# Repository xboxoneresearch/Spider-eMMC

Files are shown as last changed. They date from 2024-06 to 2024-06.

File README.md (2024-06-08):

# Spider-eMMC
KiCad 7.0 projects for SpiderUnifiedBoard and SpiderCarrierBoard, Xbox One eMMC replacement and repair boards.

_Note_: these projects are uncompleted and provided AS-IS. 

## Why?
Lack of time, resources and motivation to finish the project. Passing off the torch.
This was meant to be a complete solution to repair Xbox One consoles with damaged / degraded eMMCs. The main board would be put in the console (with minimal soldering needed), and then you could swap different eMMC modules.

- The form factor of the main board is for all Xbox One PHAT variations (Durango/Graybull, Carmel, Silverton) **and you can reuse it directly!** (this is the Edge Cuts layer in KiCad)
- The form factor is not adapted for Xbox One S nor Xbox One X

## Theory of Operation
- Xbox One's southbridge uses the whole 8-bit bus to connect to the eMMC, so it cannot be replaced by cheaper and easier eMMC compatible memories (i.e.: microSD cards)
- To minimize desoldering of ICs: You would cut the traces from the original eMMC in the board to the southbrige.
- Then you would solder this board and connect the new data and control lines, at which point the southbridge will start communicating with the new and fresh eMMC on the Spider board (or in the carrier board)

## Spider Unified Board
First prototype eMMC replacement board. This board did not feature a removable eMMC yet.
This board must be modified to replace the eMMC with a socket, where you can plug the Spider Carrier Board (see below)




## Spider Carrier Board
An attachable PCB carrying an eMMC memory. This board was meant to be plugged into the main Spider board, having a B2B socket in it.




## Credits
- TorusHyperV: Original design and iteration (and killing several consoles for science)
- XBR Team: invaluable feedback and idea of the removable eMMC board
- Betatesters: for their invaluable help and courage to test early board prototypes
  - SheezNeez
  - Wolf
  - ModzvilleUSA
  - mc_quezada
  - Heathenhkr

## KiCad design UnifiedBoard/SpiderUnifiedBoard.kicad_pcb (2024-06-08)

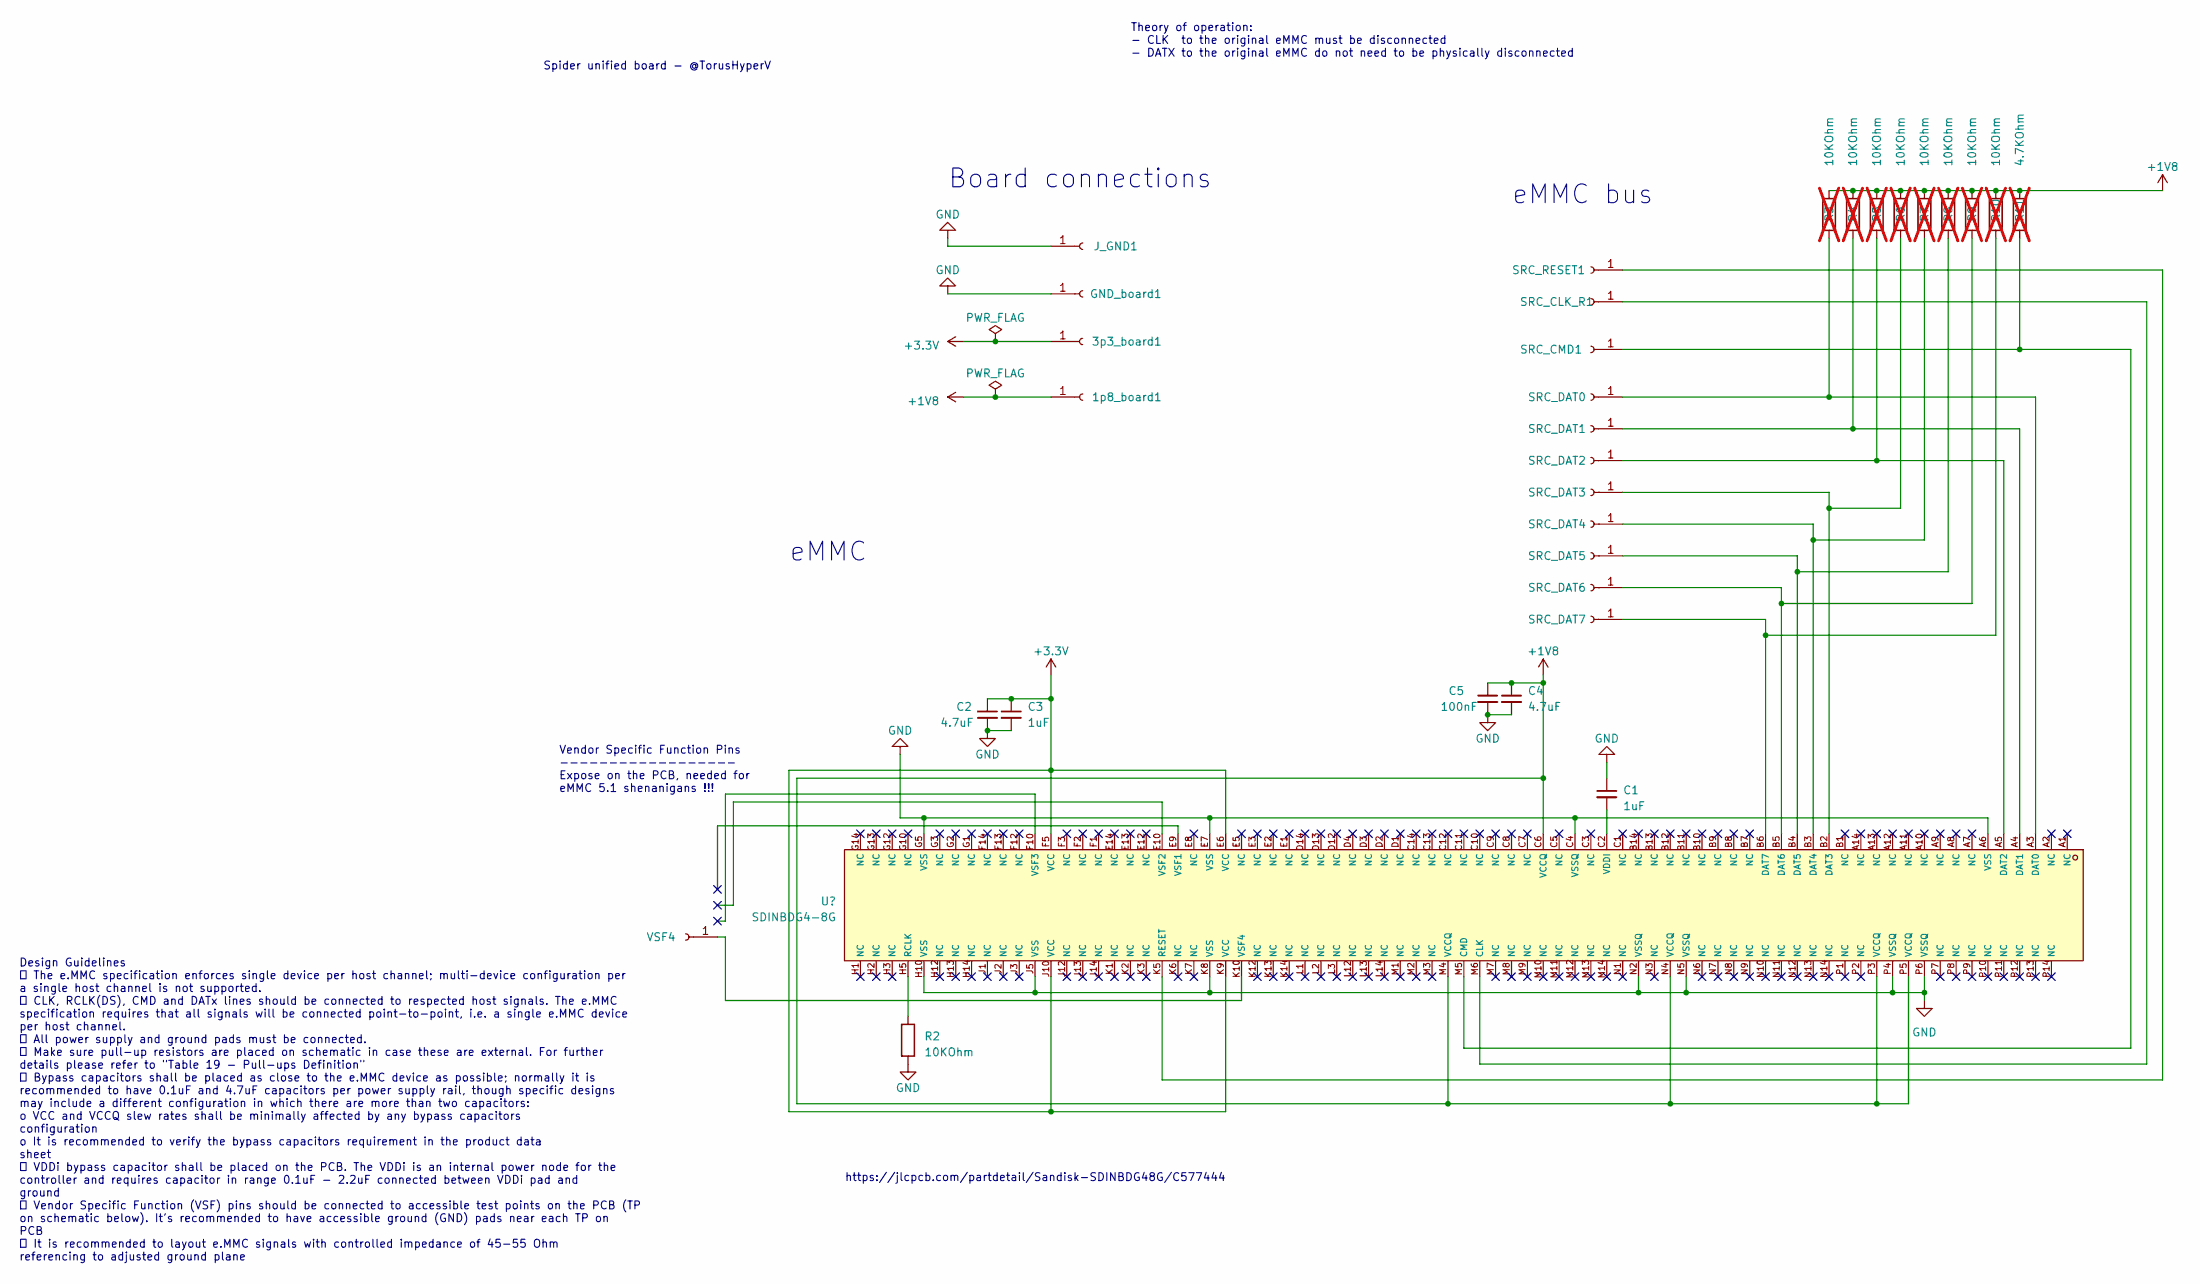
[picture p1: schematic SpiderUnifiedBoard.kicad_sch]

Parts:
1p8_board1, 3p3_board1: Conn_01x01_Female; TestPoint_Pad_D2.0mm
C1, C3: 1uF; C_0402_1005Metric
C2, C4: 4.7uF; C_0402_1005Metric
C5: 100nF; C_0402_1005Metric
GND_board1: Conn_01x01_Female; TestPoint_Pad_D2.0mm
J_GND1: Conn_01x01_Female; TestPoint_Pad_1.0x1.0mm
R2: 10KOhm; R_0402_1005Metric
R3, R4, R5, R6, R7, R8, R9, R10: 10KOhm; R_0402_1005Metric; not fitted
R11: 4.7KOhm; R_0402_1005Metric; not fitted
SRC_CLK_R1: Conn_01x01_Female; TestPoint_Pad_1.0x1.0mm
SRC_CMD1: Conn_01x01_Female; TestPoint_Pad_D1.0mm
SRC_DAT0, SRC_DAT1, SRC_DAT2, SRC_DAT3, SRC_DAT4, SRC_DAT5, SRC_DAT6, SRC_DAT7: Conn_01x01_Female; TestPoint_Pad_D1.0mm
SRC_RESET1: Conn_01x01_Female; TestPoint_Pad_D1.0mm
VSF4: Conn_01x01_Female; TestPoint_Pad_D1.0mm

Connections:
+1V8: 1p8_board1.1, C4.1, C5.1, R3.1, R4.1, R5.1, R6.1, R7.1, R8.1, R9.1, R10.1, R11.1; also elsewhere on the board
+3.3V: 3p3_board1.1, C2.1, C3.1; also elsewhere on the board
GND: C1.1, C2.2, C3.2, C4.2, C5.2, GND_board1.1, J_GND1.1, R2.2; also elsewhere on the board
unnamed 3: SRC_CLK_R1.1; also elsewhere on the board
unnamed 4: R11.2, SRC_CMD1.1; also elsewhere on the board
unnamed 5: R3.2, SRC_DAT0.1; also elsewhere on the board
unnamed 6: R4.2, SRC_DAT1.1; also elsewhere on the board
unnamed 7: R5.2, SRC_DAT2.1; also elsewhere on the board
unnamed 8: R6.2, SRC_DAT3.1; also elsewhere on the board
unnamed 9: R7.2, SRC_DAT4.1; also elsewhere on the board
unnamed 10: R8.2, SRC_DAT5.1; also elsewhere on the board
unnamed 11: R9.2, SRC_DAT6.1; also elsewhere on the board
unnamed 12: R10.2, SRC_DAT7.1; also elsewhere on the board
unnamed 13: SRC_RESET1.1; also elsewhere on the board
unnamed 14: R2.1; also elsewhere on the board
unnamed 15: C1.2; also elsewhere on the board
unnamed 16: VSF4.1; also elsewhere on the board

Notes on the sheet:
Spider unified board - @TorusHyperV
eMMC
eMMC bus
Design Guidelines  The e.MMC specification enforces single device per host channel; multi-device configuration per a single host channel is not supported.  CLK, RCLK(DS), CMD and DATx lines should be connected to respected host signals. The e.MMC specification requires that all signals will be co…
Vendor Specific Function Pins ------------------ Expose on the PCB, needed for eMMC 5.1 shenanigans !!!
https://jlcpcb.com/partdetail/Sandisk-SDINBDG48G/C577444
Board connections
Theory of operation: - CLK to the original eMMC must be disconnected - DATX to the original eMMC do not need to be physically disconnected

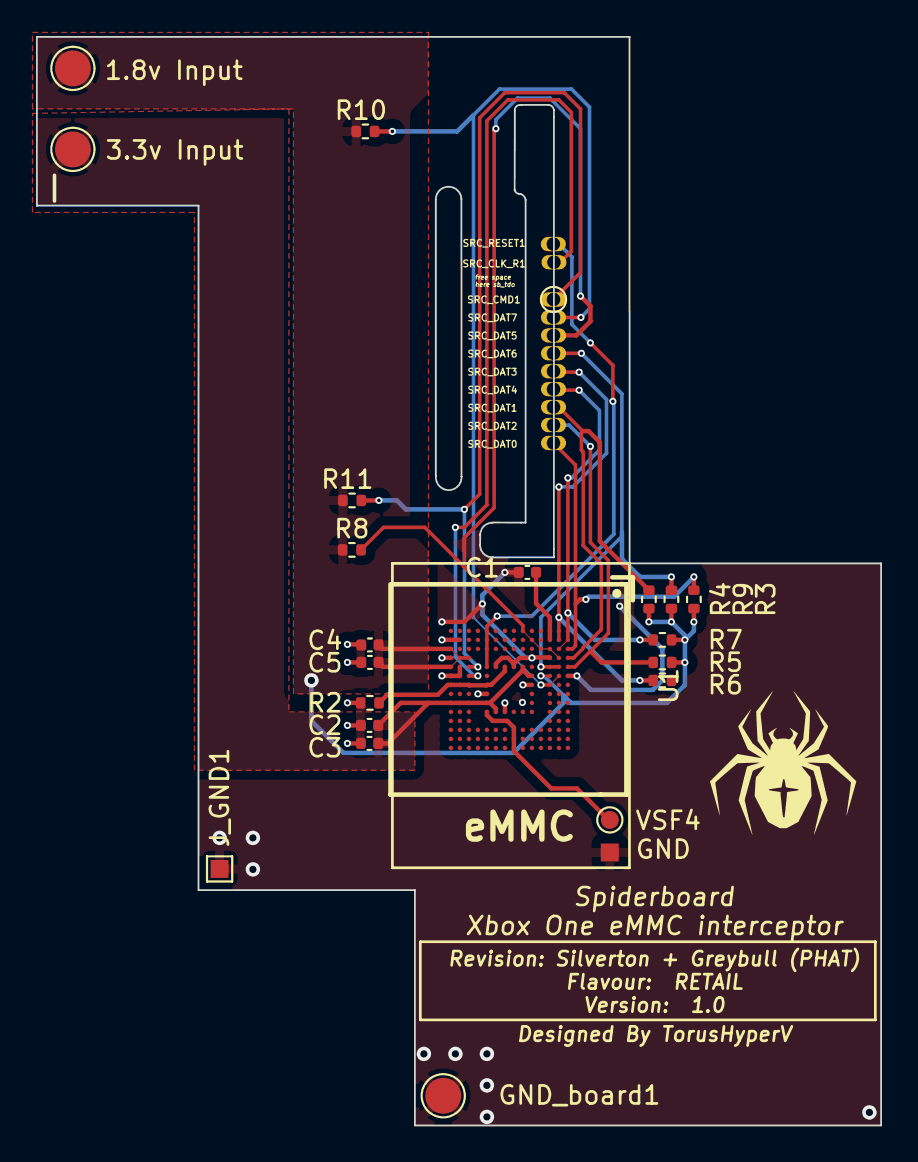
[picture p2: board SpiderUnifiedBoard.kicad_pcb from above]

Board: 2 copper layers, 46.9 x 60.5 mm, 32 parts (0 on the bottom side), 17 nets.

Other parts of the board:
1.8v Input, 3.3v Input: Conn_01x01_Female; TestPoint_Pad_D2.0mm
U1: SDINBDG4-8G; FBGA-153_L13.0-W11.5-P0.50_KLMAG1JETD-B041

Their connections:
+1V8: 1.8v Input.1, U1.C6 (VCCQ), U1.M4 (VCCQ), U1.N4 (VCCQ), U1.P3 (VCCQ), U1.P5 (VCCQ); also elsewhere on the board
+3.3V: 3.3v Input.1, U1.E6 (VCC), U1.F5 (VCC), U1.J10 (VCC), U1.K9 (VCC); also elsewhere on the board
GND: U1.A6 (VSS), U1.C4 (VSSQ), U1.E7 (VSS), U1.G5 (VSS), U1.H10 (VSS), U1.J5 (VSS), U1.K8 (VSS), U1.N2 (VSSQ), U1.N5 (VSSQ), U1.P4 (VSSQ), U1.P6 (VSSQ); also elsewhere on the board
unnamed 3: U1.M6 (CLK); also elsewhere on the board
unnamed 4: U1.M5 (CMD); also elsewhere on the board
unnamed 5: U1.A3 (DAT0); also elsewhere on the board
unnamed 6: U1.A4 (DAT1); also elsewhere on the board
unnamed 7: U1.A5 (DAT2); also elsewhere on the board
unnamed 8: U1.B2 (DAT3); also elsewhere on the board
unnamed 9: U1.B3 (DAT4); also elsewhere on the board
unnamed 10: U1.B4 (DAT5), U1.C3 (NC), U1.D3 (NC), U1.E2 (NC), U1.F1 (NC); also elsewhere on the board
unnamed 11: U1.B5 (DAT6); also elsewhere on the board
unnamed 12: U1.B6 (DAT7); also elsewhere on the board
unnamed 13: U1.K5 (RESET); also elsewhere on the board
unnamed 14: U1.H5 (RCLK); also elsewhere on the board
unnamed 15: U1.C2 (VDDI); also elsewhere on the board
unnamed 16: U1.K10 (VSF4); also elsewhere on the board

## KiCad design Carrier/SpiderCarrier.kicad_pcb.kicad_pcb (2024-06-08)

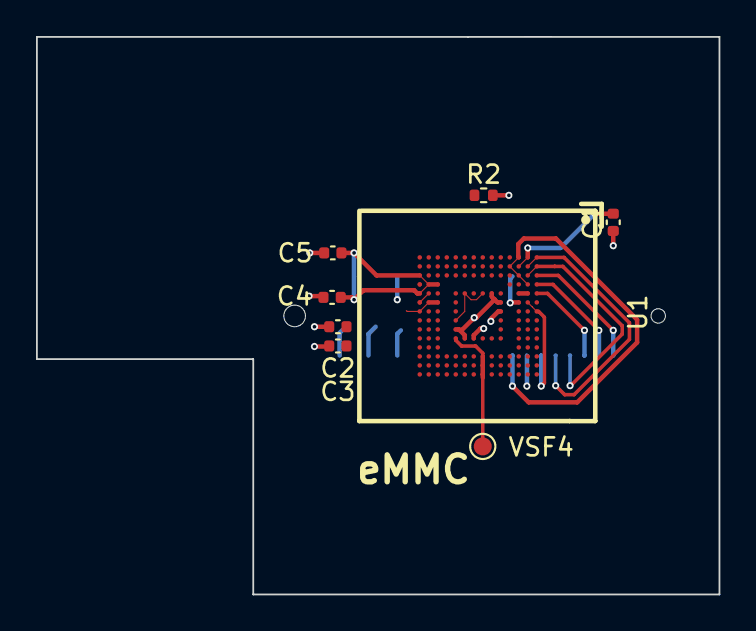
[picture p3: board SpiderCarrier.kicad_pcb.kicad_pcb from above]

Board: 2 copper layers, 37.9 x 31.0 mm, 9 parts (1 on the bottom side), 17 nets.

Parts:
C1, C3: 1uF; C_0402_1005Metric
C2, C4: 4.7uF; C_0402_1005Metric
C5: 100nF; C_0402_1005Metric
R2: 10KOhm; R_0402_1005Metric
U1: SDINBDG4-8G; FBGA-153_L13.0-W11.5-P0.50_KLMAG1JETD-B041
U4: 61082-041400LF; CONN-SMD_61082-041400LF
VSF4: Conn_01x01_Female; TestPoint_Pad_D1.0mm

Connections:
+1V8: C4.1, C5.1, U1.C6 (VCCQ), U1.M4 (VCCQ), U1.N4 (VCCQ), U1.P3 (VCCQ), U1.P5 (VCCQ), U4.3, U4.25
+3.3V: C2.1, C3.1, U1.E6 (VCC), U1.F5 (VCC), U1.J10 (VCC), U1.K9 (VCC), U4.9
GND: C1.1, C2.2, C3.2, C4.2, C5.2, R2.2, U1.A6 (VSS), U1.C4 (VSSQ), U1.E7 (VSS), U1.G5 (VSS), U1.H10 (VSS), U1.J5 (VSS), U1.K8 (VSS), U1.N2 (VSSQ), U1.N5 (VSSQ), U1.P4 (VSSQ), U1.P6 (VSSQ), U4.1, U4.17, U4.21, U4.39
unnamed: U1.M6 (CLK), U4.6
unnamed: U1.M5 (CMD), U4.10
unnamed: U1.A3 (DAT0), U4.40
unnamed: U1.A4 (DAT1), U4.38
unnamed: U1.A5 (DAT2), U4.36
unnamed: U1.B2 (DAT3), U4.32
unnamed: U1.B3 (DAT4), U4.34
unnamed: U1.B4 (DAT5), U1.C1 (NC), U4.26
unnamed: U1.B5 (DAT6), U1.C5 (NC), U4.28
unnamed: U1.B6 (DAT7), U4.30
unnamed: R2.1, U1.H5 (RCLK)
unnamed: U1.K5 (RESET), U4.2
unnamed: C1.2, U1.B1 (NC), U1.C2 (VDDI)
unnamed: U1.K10 (VSF4), VSF4.1
